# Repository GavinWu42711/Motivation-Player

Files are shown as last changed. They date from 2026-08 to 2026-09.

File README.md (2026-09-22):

# Motivation Player
An MP3-like player where WAV files of "motivational" quotes can be played from an SD card


**(Link to see it in action -> https://youtube.com/shorts/U501b-Ut6_k)**

# Motivation
I wanted to create this project as a way to learn how to make PCB's and design in CAD with minimal help from tutorials. I also often struggle with motivation and fall into the cyclical loop of "negative thoughts" so this project is meant to help break that if I'm having a bad day

# Features
- 128 x 64 OLED display to show information about what's being played
- A 30mm speaker with an LM386 audio amplifier to play sound at good quality
- Rotary encoder to scroll between quotes
- Potentiometer to adjust volume
- 2 Buttons to play quotes and randomize quotes
- Power switch to turn on and off the project (to save battery)
- SD card module to hold many recordings (Assuming ~2 mb per .WAV file, roughly 64 recordings on an 128 mb SD card)

# How It Works
Using SPI, the Pi Pico reads the .WAV files from the SD card module. Each file is named with an index (i.e 0.wav, 1.wav, e.t.c) for simplicity. Extra information about the file -- such as the name of the person who made the audio -- are stored in txt files named similarly. The Pi Pico then uses PWM to mimic DAC, with an extra capacitor and potentiometer to smooth it out. Finally, the audio passes through an LM386 audio amplifier before reaching the speaker. The LM386 was chosen due to not needing a heat sink (saving space) while still providing good quality audio. Information about the audio being played is displayed on a 128 x 64 SSD1306 through I2C. This display was chosen due to having a smaller form factor and easy to read text.

# CAD Model
The enclosure for the PCB is comprised of a bottom and a lid. The two screw together with M2 screws in each of the corner (4 total). All the parts were designed using Fusion.

**Lid**


**Bottom**




**Fully Assembled**


*Some parts such as the switch, speaker, and potentiometer are slightly off due to not having models for the ones to be used in the project. The placeholders are a way to show proof of concept*

# PCB
The PCB was designed using KiCAD. All the parts were chosen to be through hole instead of surface mount for easier soldering.

**Schematic**


**PCB**




*C5 is supposed to be a non-polarized capacitor*

**Soldered PCB**



# Firmware
Circuit Python was used to program the project as it interfaces best with the many pins of the Raspberry Pi Pico. Libraries from Adafruit were also used to interface with the OLED. The program can only read .WAV files from the SD card, with the SD card being formatted in FAT32 and the .WAV files being mono-channel, 16-bit, 22kHz.

The "lib" folder in the "Firmware" folder contains the library files that need to be uploaded to the Pi Pico in addition to the code and Circuit Python. These imports include "adafruit_display_text" and "adafruit_displayio_ssd1306". Other imports are part of Circuit Python.

# BOM
- 1 Raspberry Pi Pico
- 1 rotary encoder
- 1 potentiometer
- 1 SSD1306 (128 x 64)
- 1 micro SD card module
- 2 push buttons
- 1 SPST switch
- 1 3xAA battery holder module
- 1 LM3886
- 1 30mm speaker
- 1 0.05 uF (50 nF) capacitor (non-polarized)
- 1 10 uF capacitor (polarized)
- 1 10 uF capacitor (non-polarized)
- 2 100 uF capacitors (polarized)
- 1 250 uF capacitor (polarized)
- 3 AA batteries
- 1 SD card (any size works)
- Pinheaders
- 3D printed enclosure
- PCB
- 4 M2 Screws

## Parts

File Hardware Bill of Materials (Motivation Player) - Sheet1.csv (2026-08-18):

Item Name | Qty | Price (total) (USD) | Item link | Notes
Raspberry Pi Pico | 1 | $10.90 | https://www.amazon.ca/Raspberry-Pi-SC1631-Pico-2/dp/B0DCKH85WR/ | Needs pin headers
Rotary Encoder | 1 | $0.00 | N/A | Already have this item
Potentiometer | 1 | $0.00 | N/A | Already have this item
SSD1306 | 1 | $0.00 | N/A | Already have this item
Mini SD Card Module | 1 | $11.39 | https://www.amazon.ca/Hutomwua-Adapter-Reader-Module-Interface/dp/B0FYKCCMLY/
Push Button | 2 | $0.00 | N/A | Already have this item
SPST switch | 1 | $9.76 | https://www.amazon.ca/Gebildet-2-Terminal-2-Position-Miniature-Electronic/dp/B0C3QZ4W6N/?th=1
3xAA Battery Holder | 1 | $10.05 | https://www.amazon.ca/LampVPath-Battery-Holder-Leads-Wires/dp/B07WRQ3XTJ/
LM386 | 1 | $7.23 | https://www.amazon.ca/DKARDU-LM386N-Amplifier-Voltage-Regulator/dp/B0C13JTR7X/
30mm Speaker | 1 | $10.03 | https://www.amazon.ca/Gikfun-Speaker-Diameter-Arduino-Speakers/dp/B07BFTYY6L/
10 uF capacitor (polarized) | 1 | $0.00 | N/A | Already have this item
10 uF capacitor (non-polarized) | 1 | $0.00 | N/A | Part of ceramic capacitor kit
100 uF capacitor (polarized) | 2 | $0.00 | N/A | Already have this item
250 uF capacitor (polarized) | 1 | $0.00 | https://www.amazon.ca/Swpeet-Electrolytic-Capacitors-0-1uF%EF%BC%8D1000uF-Assortment/dp/B07KC99W2K/ | to be bought with own money
50 nF (0.05 uF) capacitor (non-polarized) | 1 | $0.00 | https://www.amazon.ca/Tnisesm-Assortment-0-1uF-100nF-Monolithic-Multilayer/dp/B08DNF191P/?th=1 | to be bought with own money
AA battery | 3 | $0.00 | N/A | Already have this item
SD card | 1 | $2.08 | https://www.amazon.ca/Premium-Memory-Card-128Mb-Attractive/dp/B0GK15Y4Q2/
Pinheaders | 1 | $2.44 | https://www.amazon.ca/Replacement-Straight-Durable-Industrial-Components/dp/B0GKR4V8KP/ | For the Raspberry Pi
3D printed enclosure | 1 | $0.00 | N/A | Printed by myself
M2 Screws | 4 | $0.00 | N/A | Already have this item
PCB | 1 | $20.92 | JLCPCB | PCB files in repository
Total Price (USD): | $84.80

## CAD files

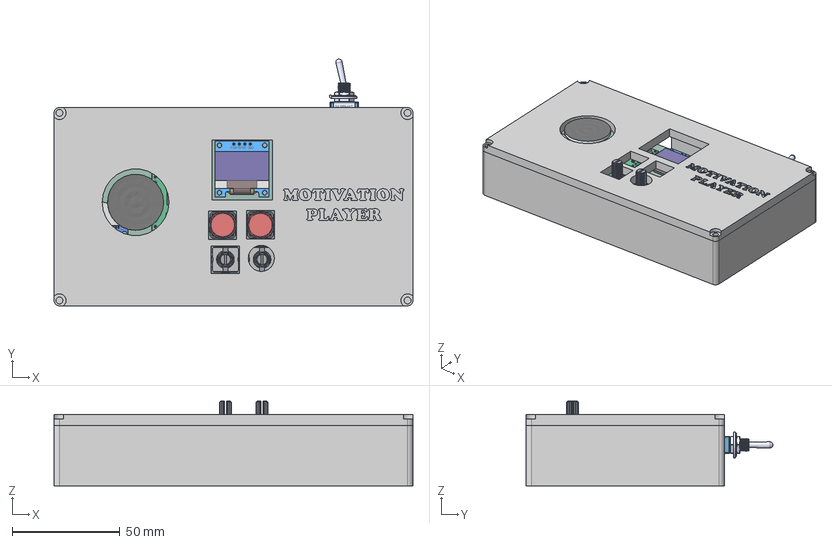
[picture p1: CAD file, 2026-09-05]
CAD/Assembled Motivation Player.step
166.5 x 114.4 x 39.3 mm

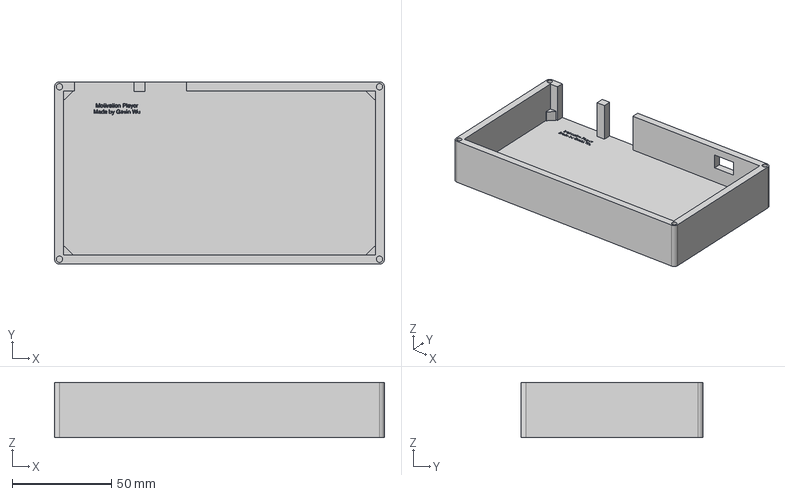
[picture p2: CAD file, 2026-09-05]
CAD/Motivation Player Bottom.step
166.5 x 92.0 x 28.0 mm

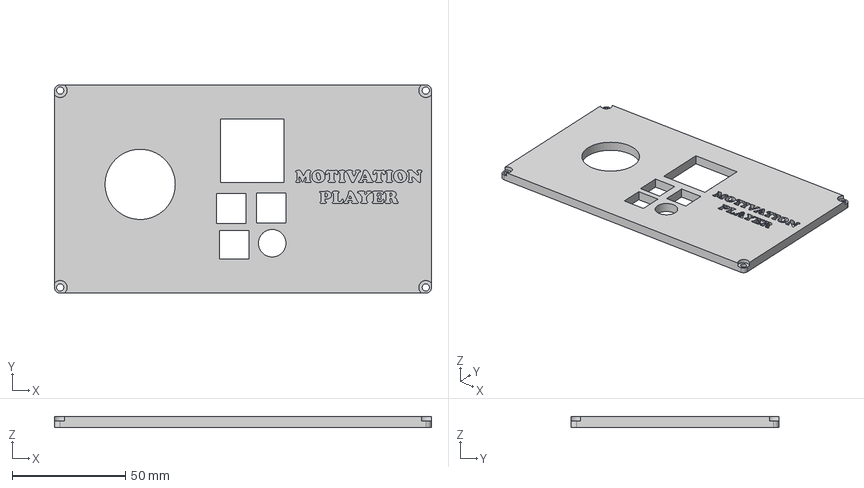
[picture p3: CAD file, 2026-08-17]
CAD/Motivation Player Top.step
166.5 x 92.0 x 5.00 mm

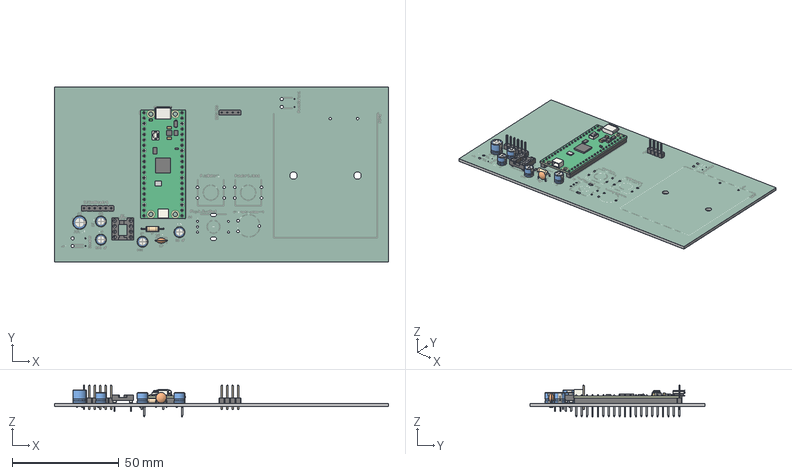
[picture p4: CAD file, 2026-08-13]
CAD/Motivation Player.step
156.5 x 82.0 x 14.9 mm
CP_Radial_D5.0mm_P2.50mm x 4
PinHeader_1x06_P2.54mm_Vertical
C_Disc_D5.0mm_W2.5mm_P5.00mm
DIP-8_W7.62mm_Socket
CP_Radial_D6.3mm_P2.50mm
RaspberryPi_Pico_H_Module_KiCad
RaspberryPi_Pico_Header_DIP-40_H2.54mm_KiCad
R_Axial_DIN0207_L6.3mm_D2.5mm_P10.16mm_Horizontal
PinHeader_1x04_P2.54mm_Vertical
Motivation Player_silkscreen
Motivation Player_soldermask x 2
Motivation Player_PCB

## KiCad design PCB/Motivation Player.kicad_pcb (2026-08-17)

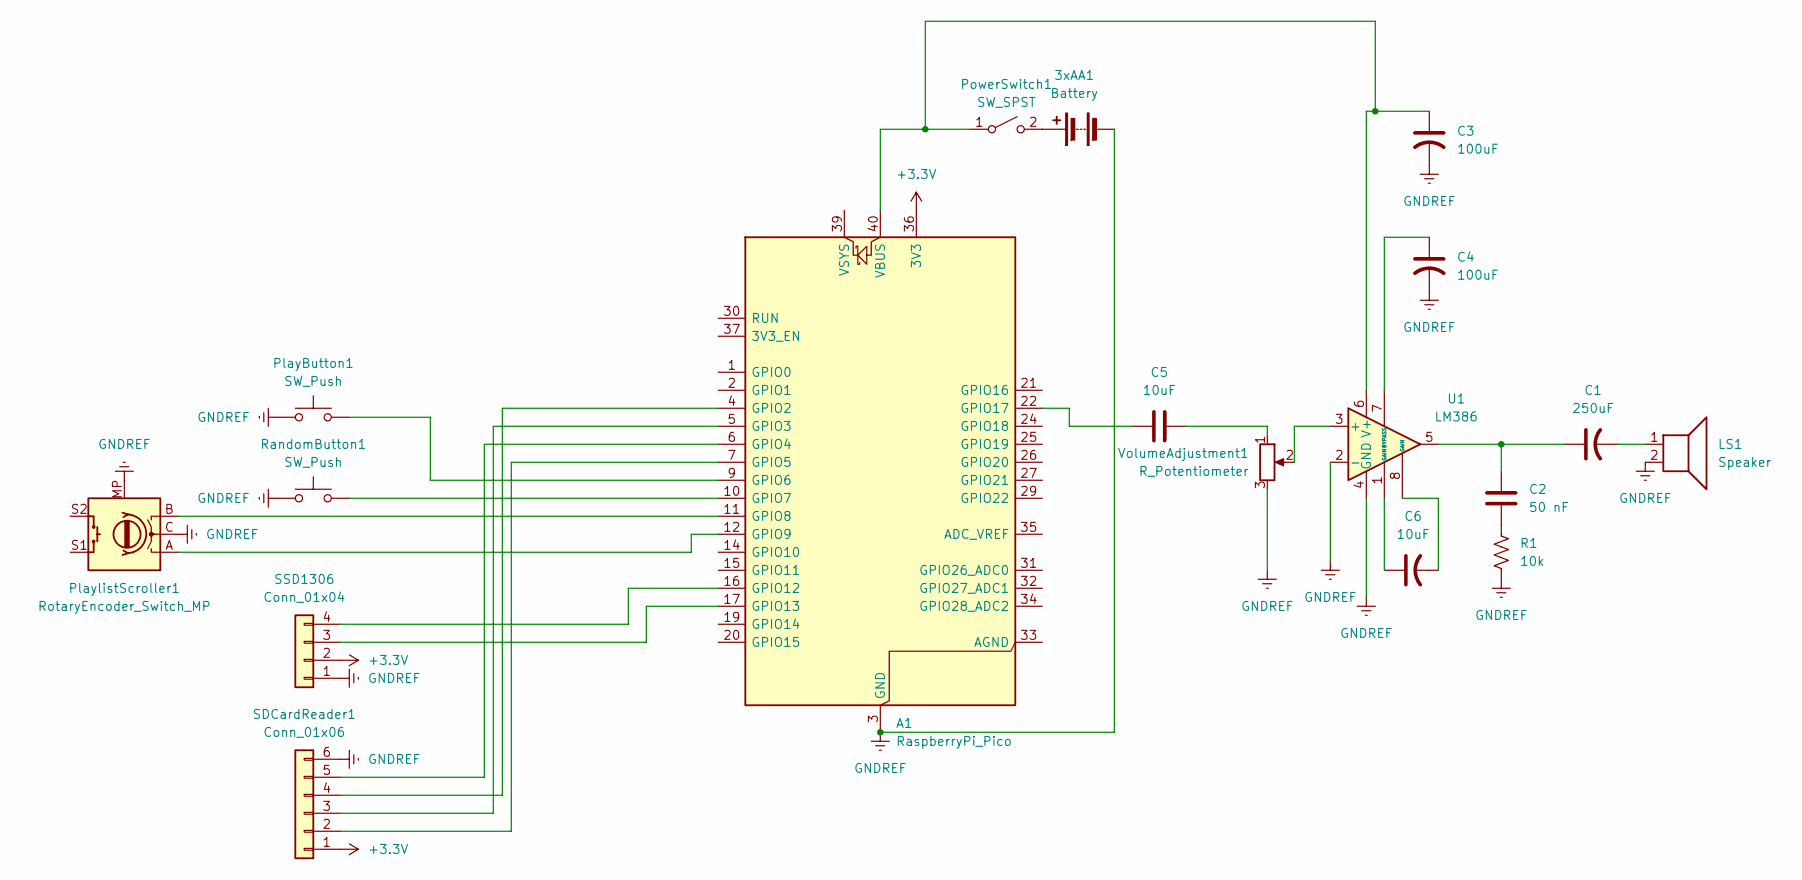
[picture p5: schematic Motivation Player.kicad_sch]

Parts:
3xAA1: Battery; BatteryHolder_TruPower_BH-331P_3xAA
A1: RaspberryPi_Pico; RaspberryPi_Pico_Common_THT
C1: 250uF; CP_Radial_D6.3mm_P2.50mm
C2: 50 nF; C_Disc_D5.0mm_W2.5mm_P5.00mm
C3, C4: 100uF; CP_Radial_D5.0mm_P2.50mm
C5, C6: 10uF; CP_Radial_D5.0mm_P2.50mm
LS1: Speaker; SolderWire-0.1sqmm_1x02_P3.6mm_D0.4mm_OD1mm_Relief
PlayButton1: SW_Push; SW_PUSH-12mm
PlaylistScroller1: RotaryEncoder_Switch_MP; RotaryEncoder_Alps_EC11E-Switch_Vertical_H20mm
PowerSwitch1: SW_SPST; SolderWire-0.1sqmm_1x02_P3.6mm_D0.4mm_OD1mm_Relief
R1: 10k; R_Axial_DIN0207_L6.3mm_D2.5mm_P10.16mm_Horizontal
RandomButton1: SW_Push; SW_PUSH-12mm
SDCardReader1: Conn_01x06; PinHeader_1x06_P2.54mm_Vertical
SSD1306: Conn_01x04; PinHeader_1x04_P2.54mm_Vertical
U1: LM386; DIP-8_W7.62mm_Socket
VolumeAdjustment1: R_Potentiometer; Potentiometer_Piher_PT-10-V10_Vertical

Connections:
+3.3V: A1.36 (3V3), SDCardReader1.1, SSD1306.2
GNDREF: 3xAA1.2 (-), A1.3 (GND), A1.8 (GND), A1.13 (GND), A1.18 (GND), A1.23 (GND), A1.28 (GND), A1.38 (GND), C3.2, C4.2, LS1.2, PlayButton1.1, PlaylistScroller1.C, PlaylistScroller1.MP, R1.2, RandomButton1.1, SDCardReader1.6, SSD1306.1, U1.2 (-), U1.4 (GND), VolumeAdjustment1.3; also elsewhere on the board
unnamed: 3xAA1.1 (+), PowerSwitch1.2 (B)
unnamed: A1.4 (GPIO2), SDCardReader1.4
unnamed: A1.5 (GPIO3), SDCardReader1.3
unnamed: A1.6 (GPIO4), SDCardReader1.5
unnamed: A1.7 (GPIO5), SDCardReader1.2
unnamed: A1.9 (GPIO6), PlayButton1.2
unnamed: A1.10 (GPIO7), RandomButton1.2
unnamed: A1.11 (GPIO8), PlaylistScroller1.B
unnamed: A1.12 (GPIO9), PlaylistScroller1.A
unnamed: A1.16 (GPIO12), SSD1306.4
unnamed: A1.17 (GPIO13), SSD1306.3
unnamed: A1.22 (GPIO17), C5.1
unnamed: A1.40 (VBUS), C3.1, PowerSwitch1.1 (A), U1.6 (V+)
unnamed: C1.1, C2.1, U1.5
unnamed 16: C1.2, LS1.1; also elsewhere on the board
unnamed: C2.2, R1.1
unnamed: C5.2, VolumeAdjustment1.1
unnamed: C6.1, U1.1 (GAIN)
unnamed: C6.2, U1.8 (GAIN)
unnamed: U1.3 (+), VolumeAdjustment1.2
unnamed: C4.1, U1.7 (BYPASS)

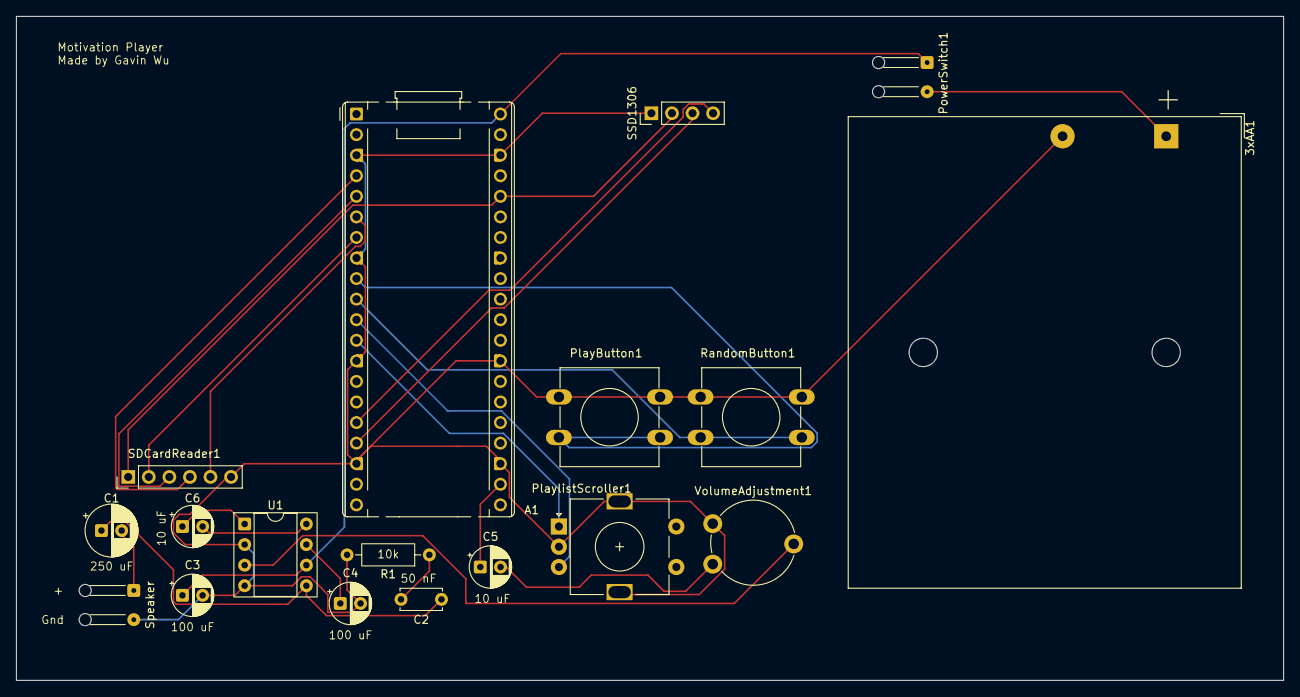
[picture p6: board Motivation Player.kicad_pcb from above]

Board: 2 copper layers, 156.5 x 82.0 mm, 18 parts (0 on the bottom side), 23 nets.

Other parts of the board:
Speaker: Speaker; SolderWire-0.1sqmm_1x02_P3.6mm_D0.4mm_OD1mm_Relief

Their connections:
GNDREF: Speaker.2; also elsewhere on the board
unnamed 16: Speaker.1; also elsewhere on the board

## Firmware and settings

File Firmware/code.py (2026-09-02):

import board
import digitalio
import time
import random
import busio
import storage
import rotaryio
import sdcardio
from audiocore import WaveFile
from audiopwmio import PWMAudioOut as AudioOut
import displayio
from adafruit_display_text import label
from i2cdisplaybus import I2CDisplayBus
import adafruit_displayio_ssd1306
import terminalio

#Setup SSD1306
displayio.release_displays()
SCL = board.GP13
SDA = board.GP12
i2c = busio.I2C(SCL, SDA)
display_bus = I2CDisplayBus(i2c, device_address=0x3C)
display = adafruit_displayio_ssd1306.SSD1306(display_bus, width=128, height=64)
splash = displayio.Group()
display.root_group = splash

#Setup speaker
SPEAKER_PIN = board.GP17
speaker = AudioOut(SPEAKER_PIN)

#Setup the play button
play_btn = digitalio.DigitalInOut(board.GP6)
play_btn.switch_to_input(pull = digitalio.Pull.UP)
play_btn_pressed = False

#Setup for the random button
rand_btn = digitalio.DigitalInOut(board.GP7)
rand_btn.switch_to_input(pull = digitalio.Pull.UP)
rand_btn_pressed = False

#Setup rotary encoder scroller
A_PIN = board.GP8
B_PIN = board.GP9
scroll_encoder = rotaryio.IncrementalEncoder(A_PIN, B_PIN)
last_position = scroll_encoder.position

#Index of the current audio to play
audio_index:int = 0
MAX_INDEX = 62

#SD card pins
SCK = board.GP2
MOSI = board.GP3
MISO = board.GP4
CS = board.GP5

#Set up SDcard
spi = busio.SPI(SCK, MOSI, MISO)
sdcard = sdcardio.SDCard(spi,CS)

#Mount SDcard file
vfs = storage.VfsFat(sdcard)
storage.mount(vfs, "/sd")

#Setup texts on the display
TITLE_TEXT = "MOTIVATION PLAYER"
TITLE_TEXT_AREA = label.Label(terminalio.FONT, text = TITLE_TEXT, color = 0xFFFFFF, x = 15, y = 8)
splash.append(TITLE_TEXT_AREA)

index_text = "Audio #0"
index_text_area = label.Label(terminalio.FONT, text=index_text, color=0xFFFFFF, x=28, y=24)
splash.append(index_text_area)

name_text = "- testtest"
name_text_area = label.Label(terminalio.FONT, text=name_text, color=0xFFFFFF, x=28, y=40)
splash.append(name_text_area)

#Play an audio file based on the index passed in
def play_audio(index:int):

    #Stop any audio from play if there is audio playing
    if speaker.playing:
        speaker.pause()

    try:
        wave_file = open("/sd/" + str(index) + ".wav", "rb")
        wave = WaveFile(wave_file)
        speaker.play(wave) 
    except Exception:
        print("Error playing audio")
        print("Error: " + str(Exception))

#Update the display to show the current audio file playing/to be played
def update_display(index:int):  
    index_text_area.text = "Audio #" + str(index + 1)

    #Get name of person who gave quote in from a txt file
    try:
        with open("/sd/" + str(index) + ".txt","r") as file:
            name = file.readline().strip()
            name_text_area.text = "- " + name
    except:
        name_text_area.text = "- Anonymous"

#Make it so on boot-up, the first audio is shown
update_display(0)

#Main loop
while True:

    #Check if the current encoder's position has changed. If it has, change the audio index
    #chosen accordingly
    position = scroll_encoder.position

    if position != last_position:
        #Get how many ticks have happened
        delta_index = position - last_position
        audio_index += delta_index

        #Make sure the index doesn't exceed the max and min index
        if audio_index < 0:
            audio_index += MAX_INDEX
        elif audio_index > MAX_INDEX:
            audio_index -= MAX_INDEX

        #Update display
        update_display(audio_index)

        #Update last position
        last_position = position

    #Check if the randomization button is pressed
    if not rand_btn.value and not rand_btn_pressed:
        rand_btn_pressed = True

        #Set the index to a random number
        audio_index = random.randint(0,MAX_INDEX)

        #Update display
        update_display(audio_index)

        #Button debounce
        time.sleep(0.2)

    elif rand_btn.value:
        rand_btn_pressed = False

    

    #Check if the play button is pressed -- inversed due to being pulled up by default
    if not play_btn.value and not play_btn_pressed:
        play_btn_pressed = True

        #Play the audio corresponding to the current index
        play_audio(audio_index)

        #Button debounce
        time.sleep(0.2)

    elif play_btn.value:
        play_btn_pressed = False

    time.sleep(0.1)

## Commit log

2026-08-09 Set-up
    Setting up kicad folder
    [Motivation Player.kicad_pcb, Motivation Player.kicad_sch]
2026-08-09 PCB Design
    Wired and designed some of the core functionalities. Looking into how to wire the audio amplifier and what type to use
    [Motivation Player.kicad_sch]
2026-08-10 PCB Schematic and Footprints
    Finished the PCB schematic and assigned the footprints
    [Motivation Player.kicad_sch]
2026-08-13 Finishing up PCB
    Finished up PCB design
    [Motivation Player.kicad_pcb, Motivation Player.kicad_sch]
2026-08-13 Finished PCB (actually)
    Fixed up parts of the PCB using DRC
    [Motivation Player.kicad_pcb, Motivation Player.step]
2026-08-17 CAD models
    Finished making the CAD models for the enclosure of the Motivation Player (also added an assembled version of it -- some parts aren't correct due to not having all the right parts needed
    [Assembled Motivation Player.step, Motivation Player Bottom.step, Motivation Player Top.step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]
2026-08-17 Creating firmware
    Created the firmware using circuitpython for the Motivation player.
2026-08-17 Cleaning up files
    Cleaned up the files and the folders to be easier to navigate
    [Assembled Motivation Player.step, Motivation Player Bottom.step, Motivation Player Top.step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]
2026-08-18 Made BOM
    made list of parts needed and total cost
    [Hardware Bill of Materials (Motivation Player) - Sheet1.csv]
2026-08-19 Necessary libraries
    Added libraries needed to run the code not baked into Circuit python
2026-08-26 Debugging
    Removed the use of const() since it was causing bugs
    [code.py]
2026-08-26 Test file and bugs
    - Created a folder with test files for the SD card to do debugging
    - Fixed bugs in the code
    - Adjusted position of the text on the OLED display
    [code.py]
2026-09-02 Debug
    Fixed bugs in the code
    [code.py]
2026-09-05 CAD
    Adjusted tolerances in CAD
    [Assembled Motivation Player.step, Motivation Player Bottom.step]
